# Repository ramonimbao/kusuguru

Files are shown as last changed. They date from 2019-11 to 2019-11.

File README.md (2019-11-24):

# Kusuguru

An 3D printable Alice-like JIS-layout TKL mechanical keyboard

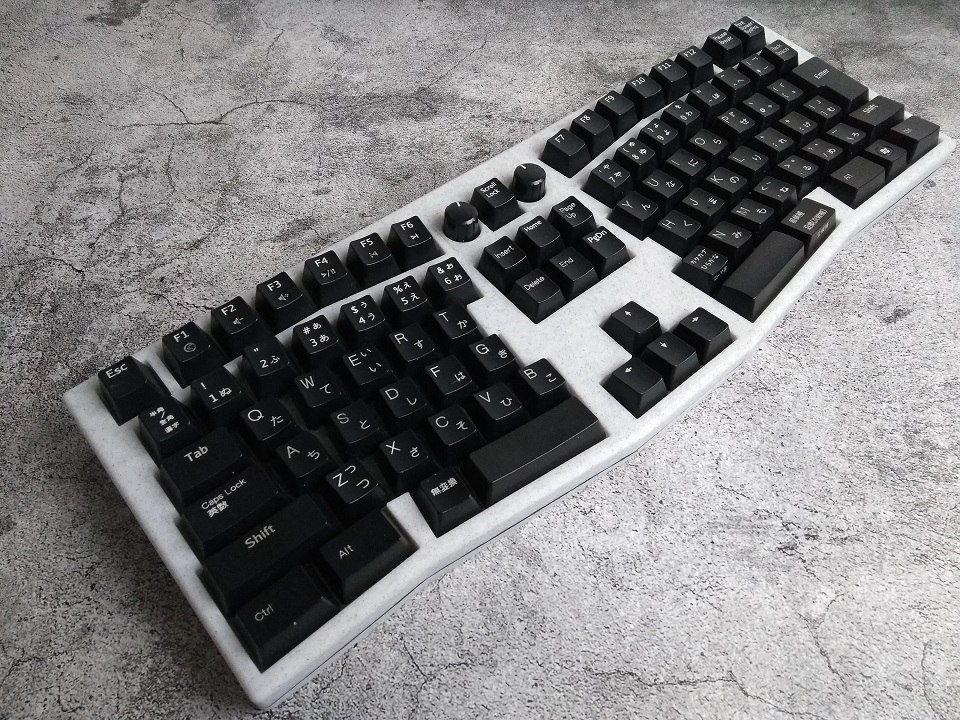
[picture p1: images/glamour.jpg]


## Layout

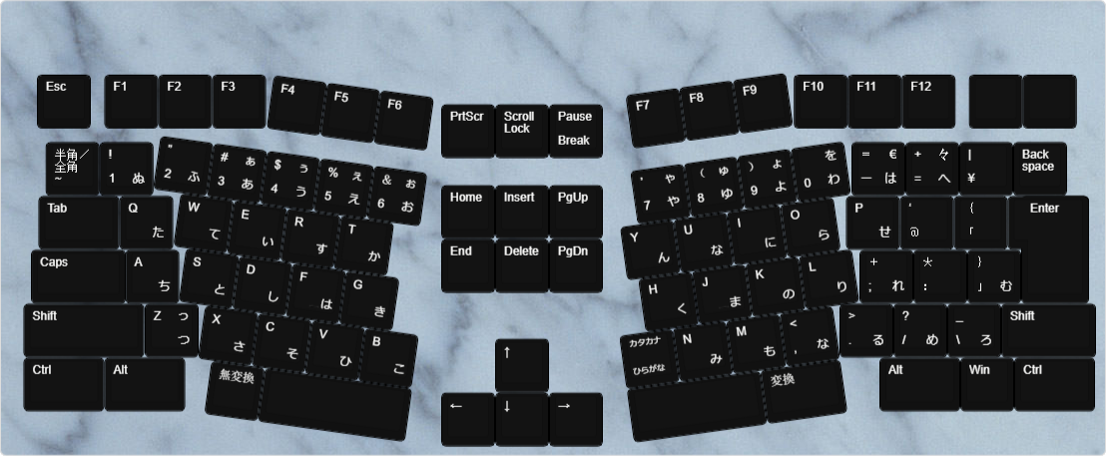
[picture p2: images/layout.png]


[Keyboard Layout Editor](http://www.keyboard-layout-editor.com/#/gists/484f5ee0a52b16d75605850b4b710184)

## Components

### Required components

- 93× switches of your choice
- 4× plate-mounted Costar stabilizers
- 93× diodes
- Wires
- 8× M3×16 countersunk screws

### Optional components

- 1× M3×16 countersunk screw
- 1× M3×25 countersunk screw
- 3D printed spacers
- 93x Kailh hotswap sockets
- 3D printed kailh hotswap socket holders (modified from ["Cherry MX Kailh Socket Holder" by peterlee, licensed CC BY 3.0](https://www.thingiverse.com/thing:3117549))
- [DFRobot EC11 rotary encoder modules](https://www.dfrobot.com/product-1611.html)
- M3×8 countersunk screws

The optional long screws are for reinforcing the top left and right halves. The short screws are for mounting encoder module(s) if needed.

You may opt for hotswap using Kailh sockets. You'd need to 3D print the accent spacers as well. I just superglued all the hotswap socket holders to the case.

## Wiring diagram

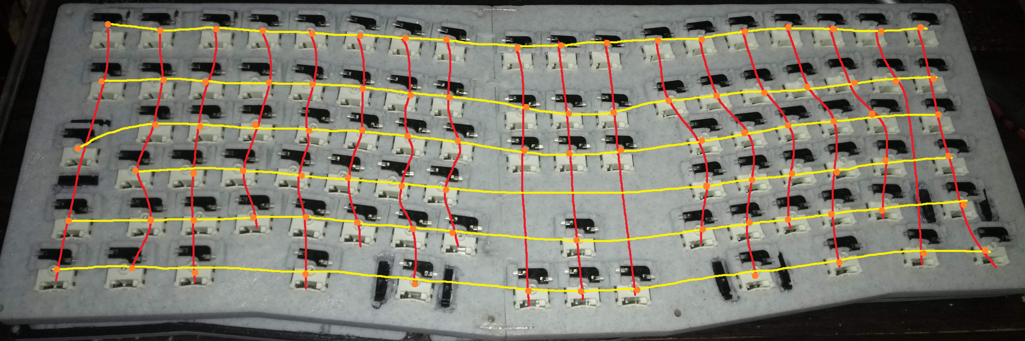
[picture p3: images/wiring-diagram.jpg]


## Build notes

The halves do not lock into each other. I used a combination of glue and diode trimmings melted into the plastic.

For gluing things together, I found [this](https://www.youtube.com/watch?v=n1meoZaHYZo) video about using super glue and baking soda about the process.

## Firmware

The firmware included is for the STM32F103 ["Blue Pill"](https://wiki.stm32duino.com/index.php?title=Blue_Pill) board.

The STM32duino bootloader is not necessary. Simply flash the board using an ST-Link programmer.

## More info

More info can be found in [this blog post](https://ramonimbao.github.io/kusuguru/).

## License

This project is licensed under the MIT license. See the `LICENSE.md` for more details.

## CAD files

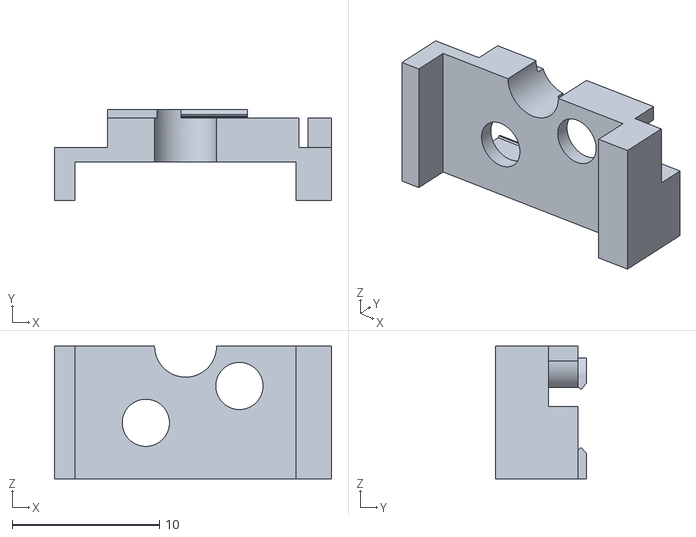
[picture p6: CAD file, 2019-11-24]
stl/1_X_Kailh_Socket_Holder.stl
18.8 x 6.15 x 9.00

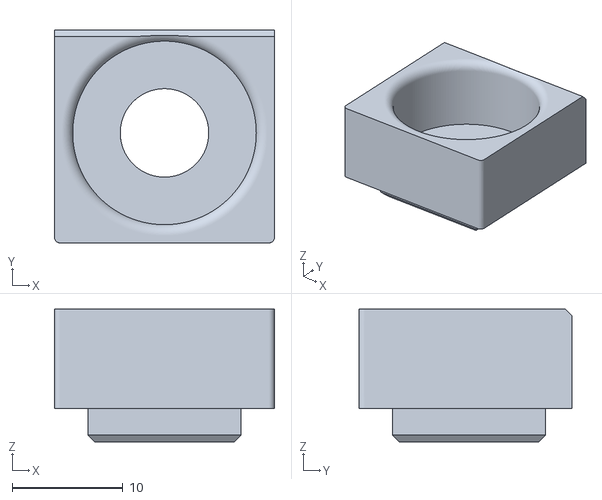
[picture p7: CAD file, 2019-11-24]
stl/Encoder_HoleCap.stl
19.9 x 19.2 x 12.0

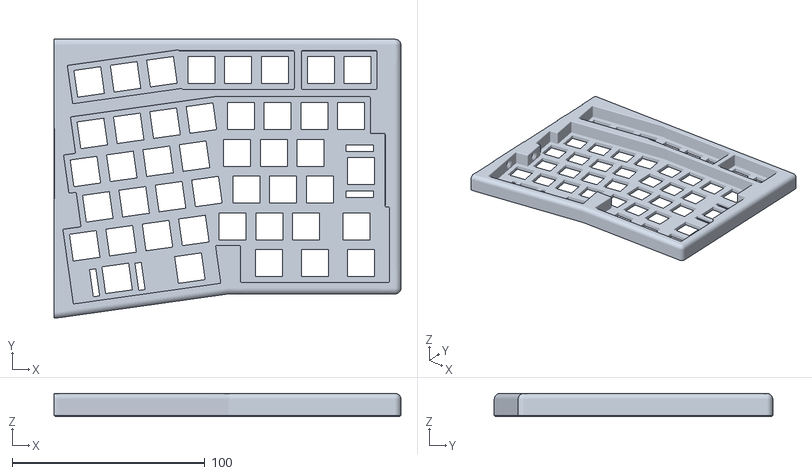
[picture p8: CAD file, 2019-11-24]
stl/AliceJIS_Top_Right.stl
179.9 x 144.4 x 12.0

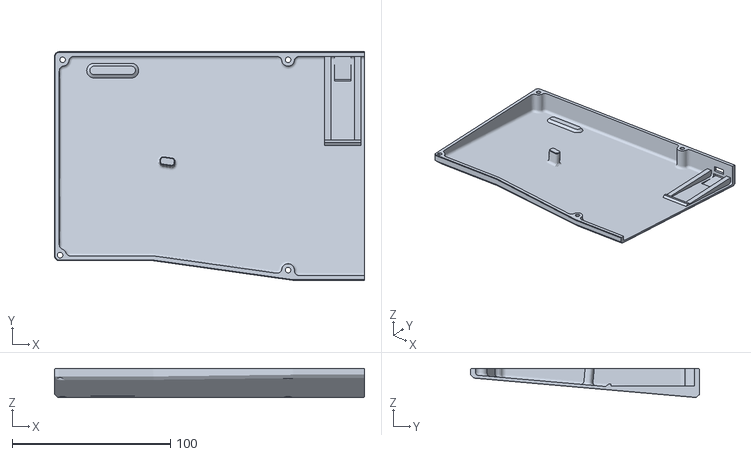
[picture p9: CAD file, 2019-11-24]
stl/AliceJIS_Bottom_Left.stl
195.9 x 144.4 x 18.5

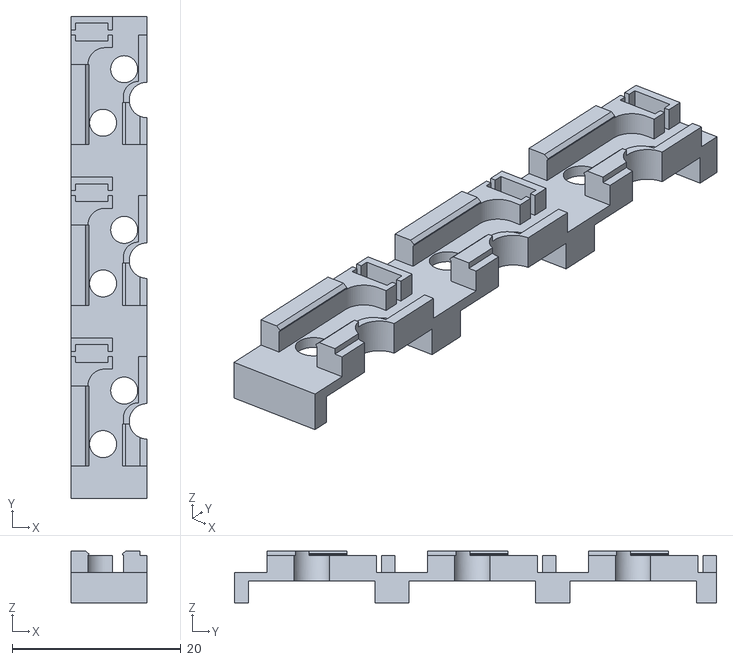
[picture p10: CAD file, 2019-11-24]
stl/3_X_Kailh_Socket_Holder.stl
9.00 x 57.2 x 6.15

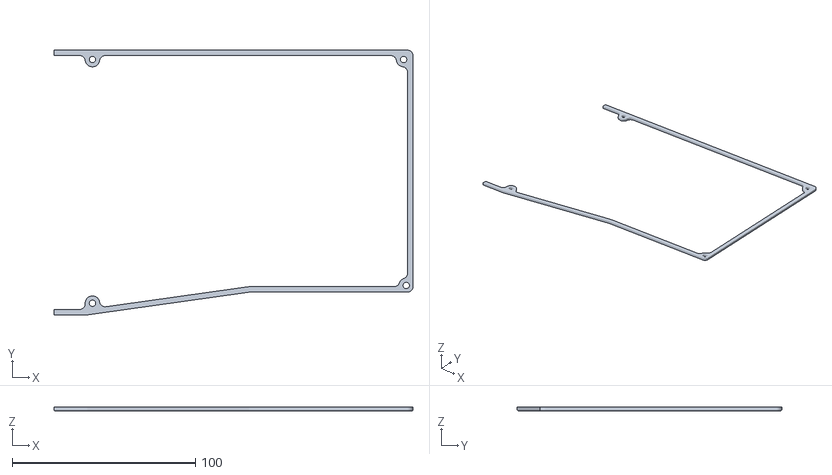
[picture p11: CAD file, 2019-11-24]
stl/AliceJIS_Spacer_Right.stl
195.9 x 144.4 x 2.00

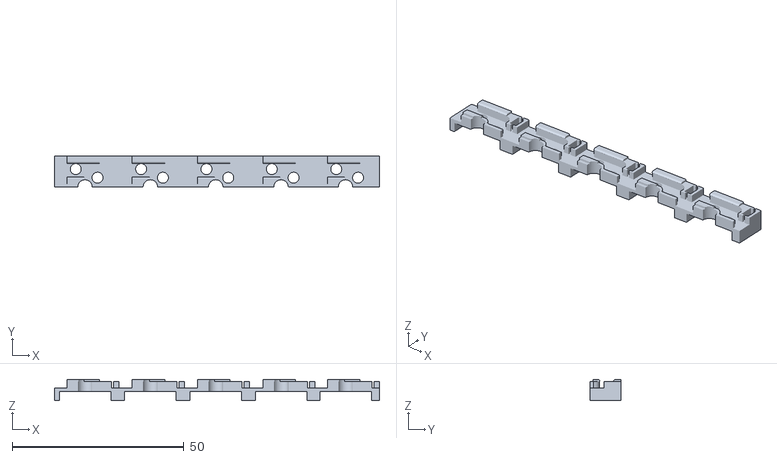
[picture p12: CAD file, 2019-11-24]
stl/5_X_Kailh_Socket_Holder.stl
94.8 x 9.00 x 6.15

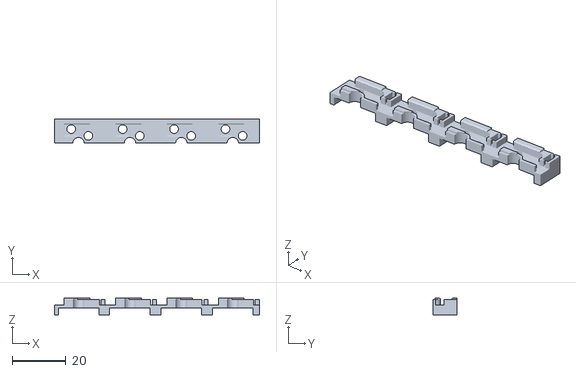
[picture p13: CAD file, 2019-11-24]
stl/4_X_Kailh_Socket_Holder.stl
76.0 x 9.00 x 6.15

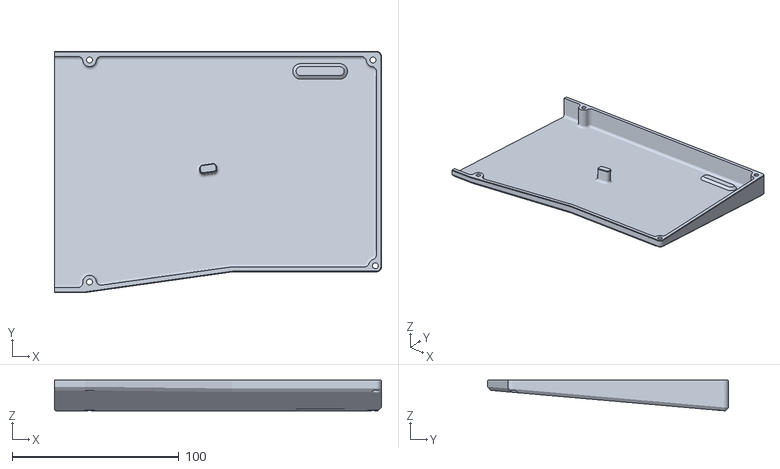
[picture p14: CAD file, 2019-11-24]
stl/AliceJIS_Bottom_Right.stl
195.9 x 144.4 x 18.5

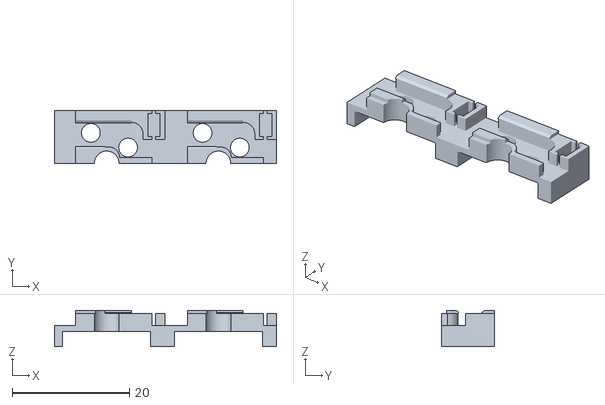
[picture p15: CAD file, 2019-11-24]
stl/2_X_Kailh_Socket_Holder.stl
37.9 x 9.00 x 6.15

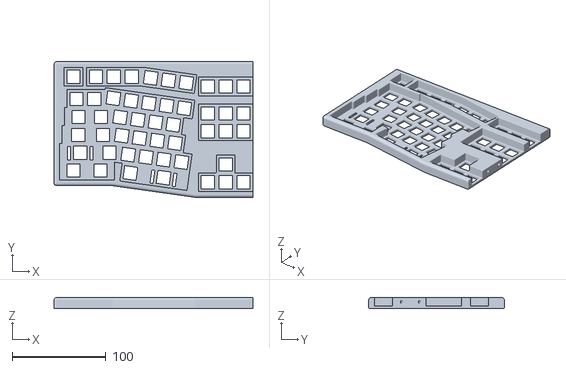
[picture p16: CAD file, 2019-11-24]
stl/AliceJIS_Top_Left.stl
211.8 x 144.4 x 12.0

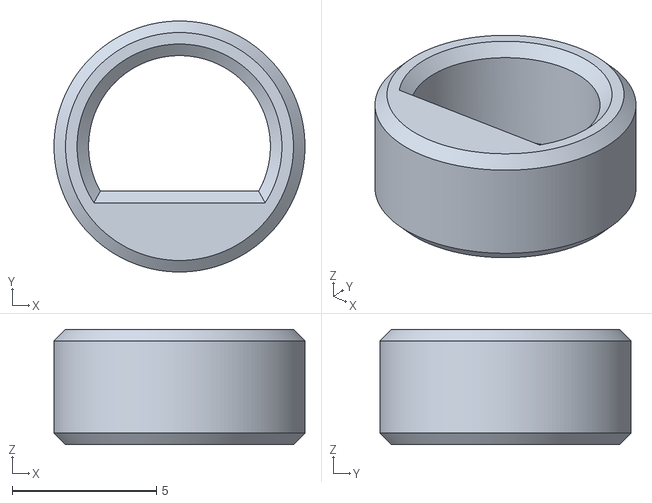
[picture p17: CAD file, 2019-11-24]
stl/Encoder_Spacer.stl
8.70 x 8.70 x 4.00

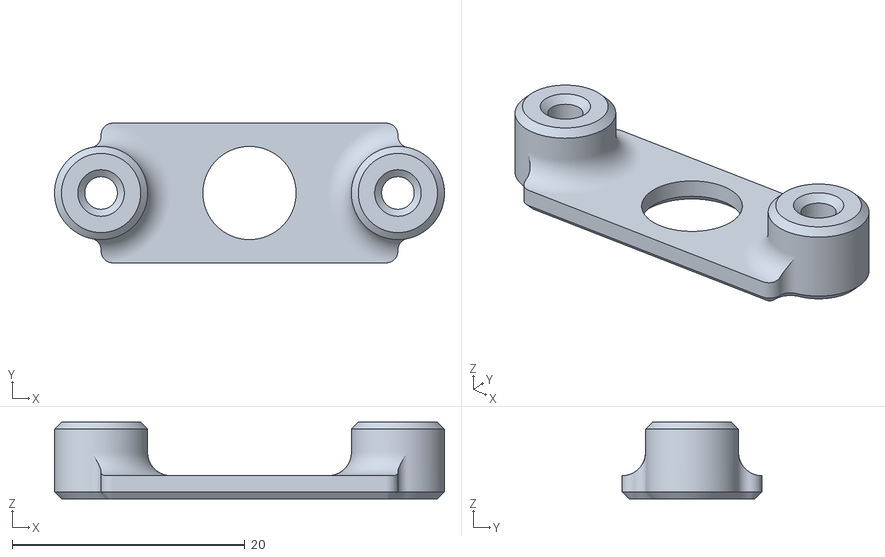
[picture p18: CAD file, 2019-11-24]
stl/Encoder_ScrewSupport.stl
33.5 x 12.0 x 6.60

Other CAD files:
stl/AliceJIS_Spacer_Left.stl
fusion360/Alice JIS TKL.f3d

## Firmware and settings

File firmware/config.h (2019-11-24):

/*
Copyright 2019 Ramon Imbao

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
You should have received a copy of the GNU General Public License
along with this program.  If not, see <http://www.gnu.org/licenses/>.
*/

#pragma once

#include "config_common.h"

/* USB Device descriptor parameter */
#define VENDOR_ID 0xB16B
#define PRODUCT_ID 0x00B5
#define DEVICE_VER 0x0069
#define MANUFACTURER Ramon Imbao
#define PRODUCT Kusuguru
#define DESCRIPTION Alice-like JIS-layout TKL keybooard

/* key matrix size */
#define MATRIX_ROWS 6
#define MATRIX_COLS 18

/*
 * Keyboard Matrix Assignments
 *
 * Change this to how you wired your keyboard
 * COLS: AVR pins used for columns, left to right
 * ROWS: AVR pins used for rows, top to bottom
 * DIODE_DIRECTION: COL2ROW = COL = Anode (+), ROW = Cathode (-, marked on diode)
 *                  ROW2COL = ROW = Anode (+), COL = Cathode (-, marked on diode)
 *
 */
#define MATRIX_ROW_PINS \
    { B11, B10, B1, B0, A7, A6 }
#define MATRIX_COL_PINS \
    { A10, A15, B3, B4, B5, B6, B7, B8, B9, A5, A4, A3, A2, A1, A0, C15, C14, C13 }
#define UNUSED_PINS

/* COL2ROW, ROW2COL*/
#define DIODE_DIRECTION COL2ROW

/* Encoder Pin Assignments */
#define ENCODERS_PAD_A { A9, B15 }
#define ENCODERS_PAD_B { A8, B14 }

#define ENCODER_BUTTON_A B13
#define ENCODER_BUTTON_B B12

#define ENCODER_RESOLUTION 2

/*
 * Split Keyboard specific options, make sure you have 'SPLIT_KEYBOARD = yes' in your rules.mk, and define SOFT_SERIAL_PIN.
 */
#define SOFT_SERIAL_PIN D0  // or D1, D2, D3, E6

// #define BACKLIGHT_PIN B7
// #define BACKLIGHT_BREATHING
// #define BACKLIGHT_LEVELS 3

// #define RGB_DI_PIN E2
// #ifdef RGB_DI_PIN
//   #define RGBLED_NUM 16
//   #define RGBLIGHT_HUE_STEP 8
//   #define RGBLIGHT_SAT_STEP 8
//   #define RGBLIGHT_VAL_STEP 8
//   #define RGBLIGHT_LIMIT_VAL 255 /* The maximum brightness level */
//   #define RGBLIGHT_SLEEP  /* If defined, the RGB lighting will be switched off when the host goes to sleep */
// /*== all animations enable ==*/
//   #define RGBLIGHT_ANIMATIONS
// /*== or choose animations ==*/
//   #define RGBLIGHT_EFFECT_BREATHING
//   #define RGBLIGHT_EFFECT_RAINBOW_MOOD
//   #define RGBLIGHT_EFFECT_RAINBOW_SWIRL
//   #define RGBLIGHT_EFFECT_SNAKE
//   #define RGBLIGHT_EFFECT_KNIGHT
//   #define RGBLIGHT_EFFECT_CHRISTMAS
//   #define RGBLIGHT_EFFECT_STATIC_GRADIENT
//   #define RGBLIGHT_EFFECT_RGB_TEST
//   #define RGBLIGHT_EFFECT_ALTERNATING
// /*== customize breathing effect ==*/
//   /*==== (DEFAULT) use fixed table instead of exp() and sin() ====*/
//   #define RGBLIGHT_BREATHE_TABLE_SIZE 256      // 256(default) or 128 or 64
//   /*==== use exp() and sin() ====*/
//   #define RGBLIGHT_EFFECT_BREATHE_CENTER 1.85  // 1 to 2.7
//   #define RGBLIGHT_EFFECT_BREATHE_MAX    255   // 0 to 255
// #endif

/* Debounce reduces chatter (unintended double-presses) - set 0 if debouncing is not needed */
#define DEBOUNCE 5

/* define if matrix has ghost (lacks anti-ghosting diodes) */
//#define MATRIX_HAS_GHOST

/* Mechanical locking support. Use KC_LCAP, KC_LNUM or KC_LSCR instead in keymap */
#define LOCKING_SUPPORT_ENABLE
/* Locking resynchronize hack */
#define LOCKING_RESYNC_ENABLE

/* If defined, GRAVE_ESC will always act as ESC when CTRL is held.
 * This is userful for the Windows task manager shortcut (ctrl+shift+esc).
 */
// #define GRAVE_ESC_CTRL_OVERRIDE

/*
 * Force NKRO
 *
 * Force NKRO (nKey Rollover) to be enabled by default, regardless of the saved
 * state in the bootmagic EEPROM settings. (Note that NKRO must be enabled in the
 * makefile for this to work.)
 *
 * If forced on, NKRO can be disabled via magic key (default = LShift+RShift+N)
 * until the next keyboard reset.
 *
 * NKRO may prevent your keystrokes from being detected in the BIOS, but it is
 * fully operational during normal computer usage.
 *
 * For a less heavy-handed approach, enable NKRO via magic key (LShift+RShift+N)
 * or via bootmagic (hold SPACE+N while plugging in the keyboard). Once set by
 * bootmagic, NKRO mode will always be enabled until it is toggled again during a
 * power-up.
 *
 */
//#define FORCE_NKRO

/*
 * Magic Key Options
 *
 * Magic keys are hotkey commands that allow control over firmware functions of
 * the keyboard. They are best used in combination with the HID Listen program,
 * found here: https://www.pjrc.com/teensy/hid_listen.html
 *
 * The options below allow the magic key functionality to be changed. This is
 * useful if your keyboard/keypad is missing keys and you want magic key support.
 *
 */

/* key combination for magic key command */
/* defined by default; to change, uncomment and set to the combination you want */
// #define IS_COMMAND() (get_mods() == MOD_MASK_SHIFT)

/* control how magic key switches layers */
//#define MAGIC_KEY_SWITCH_LAYER_WITH_FKEYS  true
//#define MAGIC_KEY_SWITCH_LAYER_WITH_NKEYS  true
//#define MAGIC_KEY_SWITCH_LAYER_WITH_CUSTOM false
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

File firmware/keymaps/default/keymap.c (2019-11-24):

/* Copyright 2019 Ramon Imbao
 *
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
 * You should have received a copy of the GNU General Public License
 * along with this program.  If not, see <http://www.gnu.org/licenses/>.
 */
#include QMK_KEYBOARD_H

#include <quantum.h>
#include <quantum/keymap_extras/keymap_jp.h>

static bool ENCODER_A_PRESSED = false;
static bool ENCODER_B_PRESSED = false;

static uint8_t current_layer = 0;

enum ENCODER_A_LAYERS {
    VSCROLL = 0,
    VARROW,
    VOLUME,
    ZOOM,
};

enum ENCODER_B_LAYERS {
    HSCROLL = 0,
    HARROW,
    BRIGHTNESS,
    FLUX_BRIGHTNESS,
};

static enum ENCODER_A_LAYERS ENCODER_A_LAYER = VSCROLL;
static enum ENCODER_B_LAYERS ENCODER_B_LAYER = HSCROLL;

enum custom_keycodes {
    EIGO = SAFE_RANGE,
    NIHONGO,
};


// Layers
#define _ENGLISH 0
#define _JAPANESE 1
#define _SWITCHER 2

// Scroll Lock layer key
#define SWITCH LT(_SWITCHER, KC_SCROLLLOCK)

const uint16_t PROGMEM keymaps[][MATRIX_ROWS][MATRIX_COLS] = {
    [_ENGLISH] = LAYOUT(
        KC_ESC, KC_F1, KC_F2, KC_F3, KC_F4, KC_F5, KC_F6,          SWITCH,              KC_F7, KC_F8, KC_F9, KC_F10, KC_F11, KC_F12, KC_PAUSE, KC_PSCR,
        KC_GRAVE, KC_1, KC_2, KC_3, KC_4, KC_5, KC_6,      KC_INS, KC_HOME, KC_PGUP,    KC_7, KC_8, KC_9, KC_0, KC_MINS, KC_EQUAL, KC_BSLS, KC_BSPACE,
        KC_TAB, KC_Q, KC_W, KC_E, KC_R, KC_T,              KC_DEL, KC_END, KC_PGDN,     KC_Y, KC_U, KC_I, KC_O, KC_P, KC_LBRC, KC_RBRC, KC_ENTER,
        KC_CAPS, KC_A, KC_S, KC_D, KC_F, KC_G,                                          KC_H, KC_J, KC_K, KC_L, KC_SCOLON, KC_QUOTE, KC_BSLS,
        KC_LSFT, KC_Z, KC_X, KC_C, KC_V, KC_B,                     KC_UP,               KC_NO, KC_N, KC_M, KC_COMMA, KC_DOT, KC_SLASH, KC_RSFT, KC_RSHIFT,
        KC_LCTL, KC_LALT,    KC_NO, KC_SPACE,            KC_LEFT, KC_DOWN, KC_RIGHT,  KC_BSPACE, KC_NO,       KC_RALT, KC_RGUI, KC_RCTL
    ),

    [_JAPANESE] = LAYOUT(
        KC_ESC, KC_F1, KC_F2, KC_F3, KC_F4, KC_F5, KC_F6,          SWITCH,              KC_F7, KC_F8, KC_F9, KC_F10, KC_F11, KC_F12, KC_PAUSE, KC_PSCR,
        JP_ZHTG, KC_1, KC_2, KC_3, KC_4, KC_5, KC_6,       KC_INS, KC_HOME, KC_PGUP,    KC_7, KC_8, KC_9, KC_0, JP_MINS, JP_CIRC, JP_YEN, KC_BSPACE,
        KC_TAB, KC_Q, KC_W, KC_E, KC_R, KC_T,              KC_DEL, KC_END, KC_PGDN,     KC_Y, KC_U, KC_I, KC_O, KC_P, JP_AT, JP_LBRC, KC_ENTER,
        KC_CAPS, KC_A, KC_S, KC_D, KC_F, KC_G,                                          KC_H, KC_J, KC_K, KC_L, KC_SCOLON, JP_COLN, JP_RBRC,
        KC_LSFT, KC_Z, KC_X, KC_C, KC_V, KC_B,                     KC_UP,               JP_KANA, KC_N, KC_M, KC_COMMA, KC_DOT, KC_SLASH, JP_BSLS, KC_RSHIFT,
        KC_LCTL, KC_LALT,    JP_MHEN, KC_SPACE,            KC_LEFT, KC_DOWN, KC_RIGHT,  KC_BSPACE, JP_HENK,       KC_RALT, KC_RGUI, KC_RCTL
    ),

    [_SWITCHER] = LAYOUT(
        KC_NO, EIGO, NIHONGO, KC_NO, KC_NO, KC_NO, KC_NO,            SWITCH,                KC_NO, KC_NO, KC_NO, KC_NO, KC_NO, KC_NO, KC_NO, KC_NO,
        KC_NO, KC_NO, KC_NO, KC_NO, KC_NO, KC_NO,             KC_NO, KC_NO, KC_NO,          KC_NO, KC_NO, KC_NO, KC_NO, KC_NO, KC_NO, KC_NO, KC_NO,
        KC_NO, KC_NO, KC_NO, KC_NO, KC_NO, KC_NO,             KC_NO, KC_NO, KC_NO,          KC_NO, KC_NO, KC_NO, KC_NO, KC_NO, KC_NO, KC_NO, KC_NO,
        KC_NO, KC_NO, KC_NO, KC_NO, KC_NO, KC_NO,                                           KC_NO, KC_NO, KC_NO, KC_NO, KC_NO, KC_NO, KC_NO,
        KC_NO, KC_NO, KC_NO, KC_NO, KC_NO, KC_NO,                    KC_NO,                 KC_NO, KC_NO, KC_NO, KC_NO, KC_NO, KC_NO, KC_NO, KC_NO,
        KC_NO, KC_NO, KC_NO, KC_NO,                           KC_NO, KC_NO, KC_NO,          KC_NO, KC_NO, KC_NO, KC_NO, KC_NO, KC_NO
    )
};

void matrix_user_init(void) {
    // Set encoder button pins to pull-up.
    setPinInputHigh(ENCODER_BUTTON_A);
    setPinInputHigh(ENCODER_BUTTON_B);

    // Check the default layer (for encoder correctness)
    current_layer = eeconfig_read_default_layer();
}

void matrix_scan_user(void) {
    if (readPin(ENCODER_BUTTON_A) == 0) { // Encoder A pressed
        if (ENCODER_A_PRESSED == false) {
            switch (ENCODER_A_LAYER) {
                case VSCROLL:
                    ENCODER_A_LAYER = VARROW;
                    break;
                case VARROW:
                    ENCODER_A_LAYER = VOLUME;
                    break;
                case VOLUME:
                    ENCODER_A_LAYER = ZOOM;
                    break;
                case ZOOM:
                    ENCODER_A_LAYER = VSCROLL;
                    break;
            }
            ENCODER_A_PRESSED = true;
        }
    } else {
        ENCODER_A_PRESSED = false;
    }

    if (readPin(ENCODER_BUTTON_B) == 0) { // Encoder B pressed
        if (ENCODER_B_PRESSED == false) {
            switch (ENCODER_B_LAYER) {
                case HSCROLL:
                    ENCODER_B_LAYER = HARROW;
                    break;
                case HARROW:
                    ENCODER_B_LAYER = BRIGHTNESS;
                    break;
                case BRIGHTNESS:
                    ENCODER_B_LAYER = FLUX_BRIGHTNESS;
                    break;
                case FLUX_BRIGHTNESS:
                    ENCODER_B_LAYER = HSCROLL;
                    break;
            }
            ENCODER_B_PRESSED = true;
        }
    } else {
        ENCODER_B_PRESSED = false;
    }
}

bool process_record_user(uint16_t keycode, keyrecord_t *record) {
    switch (keycode) {
        case EIGO:
            if (record->event.pressed) {
                register_mods(MOD_BIT(KC_LCTL) | MOD_BIT(KC_RSHIFT));
                tap_code(KC_1);
                current_layer = _ENGLISH;
                set_single_persistent_default_layer(_ENGLISH);
            } else {
                unregister_mods(MOD_BIT(KC_LCTL) | MOD_BIT(KC_RSHIFT));
            }
            break;
        case NIHONGO:
            if (record->event.pressed) {
                register_mods(MOD_BIT(KC_LCTL) | MOD_BIT(KC_RSHIFT));
                tap_code(KC_2);
                current_layer = _JAPANESE;
                set_single_persistent_default_layer(_JAPANESE);
            } else {
                unregister_mods(MOD_BIT(KC_LCTL) | MOD_BIT(KC_RSHIFT));
            }
            break;
    }
    return true;
}
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

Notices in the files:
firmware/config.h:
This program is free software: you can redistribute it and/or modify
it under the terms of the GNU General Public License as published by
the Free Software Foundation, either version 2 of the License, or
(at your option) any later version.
